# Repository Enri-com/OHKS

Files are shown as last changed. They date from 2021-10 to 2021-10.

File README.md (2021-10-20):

# Open-hardware knob system for acceleration control operations #

## Description

The hardware has been structured on a PCB where are mounted 9 keys and a mechanical encoder.
The keys are used to simulate, at the firmware level, the pressure of one keyboard button or a combination of them. 
Each key is equipped with anti-bounce circuitry and ade-quate ESD protection to prevent a malfunction or breakdown 
of the electronics.
The microcontroller is devoted to managing the USB HID communication. 
To have multiple options in terms of hardware solutions for the microcontroller, the PCB has been realized to be 
compatible with both ARM STM32 microcontroller and Teensy LC module.

## License

Copyright INFN-LNL 2020.
This documentation describes OHKS_WFP hardware and is licensed under the
CERN OHL v. 1.2.
You may redistribute and modify this documentation under the terms of the
CERN OHL v.1.2. (http://ohwr.org/cernohl). This documentation is distributed
WITHOUT ANY EXPRESS OR IMPLIED WARRANTY, INCLUDING OF
MERCHANTABILITY, SATISFACTORY QUALITY AND FITNESS FOR A
PARTICULAR PURPOSE. Please see the CERN OHL v.1.2 for applicable
conditions

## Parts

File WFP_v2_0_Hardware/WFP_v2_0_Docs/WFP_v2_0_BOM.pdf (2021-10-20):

Qty: | Reference(s): | Value: | Part number: | Manufacturer:
2 | C1, C2 | 10pF | 0603 10pF C0G | GENERIC
10 | C3, C4,C5, C6, C7, C9, C10, C11, C12, C13 | 0.1uF | 0603 100nF X7R | GENERIC
1 | C8 | 4.7uF | 0805 4.7uF not polarized multilayer | GENERIC
1 | D1 | BAT54HT1G | BAT54HT1G | ONSEMI
2 | D2, D3 | LED | 0805 Green LED | GENERIC
2 | FB1, FB2 | WURTH_742792608 | 742792608 | WURTH
1 | J1 | Conn_01x05_Male | Connector:Conn_01x05_Male | GENERIC
1 | J2 | Conn_ARM_JTAG_SWD_10 | Connector:Conn_ARM_JTAG_SWD_10 | GENERIC
1 | J3 | USB_B_Micro_WURTH_629105150521 | 629105150521 | WURTH
4 | R1, R2, R3, R7, R23 | 0R0 | 0603 0R0 | GENERIC
15 | R4, R8, R9, R10, R11, R12, R13, R14, R15, R16, R17, R18, R19, R20, R21 | 10K | 0603 10K | GENERIC
2 | R5, R22 | 470R | 0603 470R | GENERIC
1 | R6 | 100K | 0603 100K | GENERIC
2 | SW1, SW2 | B3S-1000 | B3S-1000 | OMRON
9 | SW3, SW4, SW5, SW6, SW7, SW9, SW10, SW11, SW12 | SW_Push | MX1A-11NW | ZF
1 | SW8 | PEC11R-4215F-S24 | PEC11R-4215F-S24 | BOURNS
2 | U1, U5 | IP4220CZ6 | IP4220CZ6 | NEXPERIA
1 | U2 | Teensy-LC | Teensy-LC | PJRC
1 | U3 | STM32F042K6T7 | STM32F042K6T7 | STMICROELECTRONICS
1 | U4 | LM1117-3.3 | LM1117IMP-3.3/NOPB | TI
3 | U6, U7, U8 | SN74HCS125D-Q1 | SN74HCS125-Q | TI
1 | Y1 | NX3225GD-8MHZ-EXS00A-CG04874 | NX3225GD-8MHZ-STD-CRA-3 | NDK

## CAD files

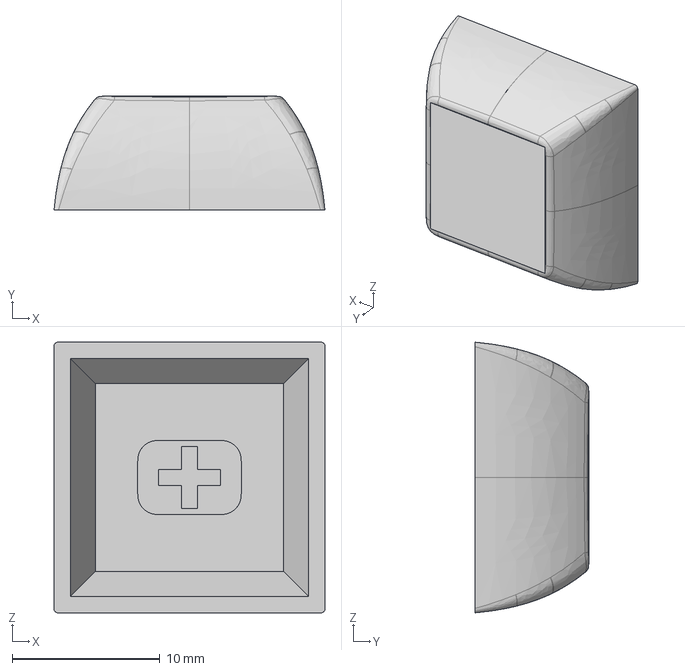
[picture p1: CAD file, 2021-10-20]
WFP_v2_0_3D-Mechanical/Sw_keycap.step
18.3 x 7.70 x 18.3 mm

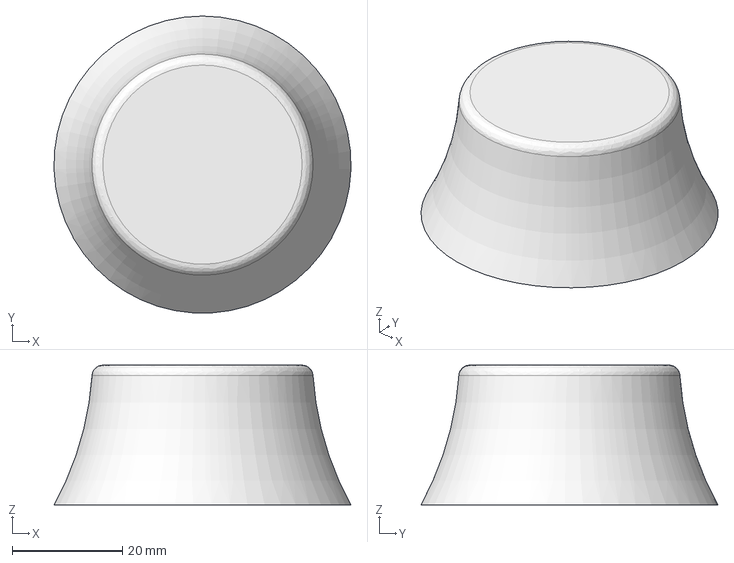
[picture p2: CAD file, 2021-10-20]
WFP_v2_0_3D-Mechanical/Encoder_knob.step
54.0 x 53.9 x 25.4 mm

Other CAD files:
WFP_v2_0_3D-Mechanical/Encoder_knob.stl
WFP_v2_0_3D-Mechanical/Sw_keycap.stl

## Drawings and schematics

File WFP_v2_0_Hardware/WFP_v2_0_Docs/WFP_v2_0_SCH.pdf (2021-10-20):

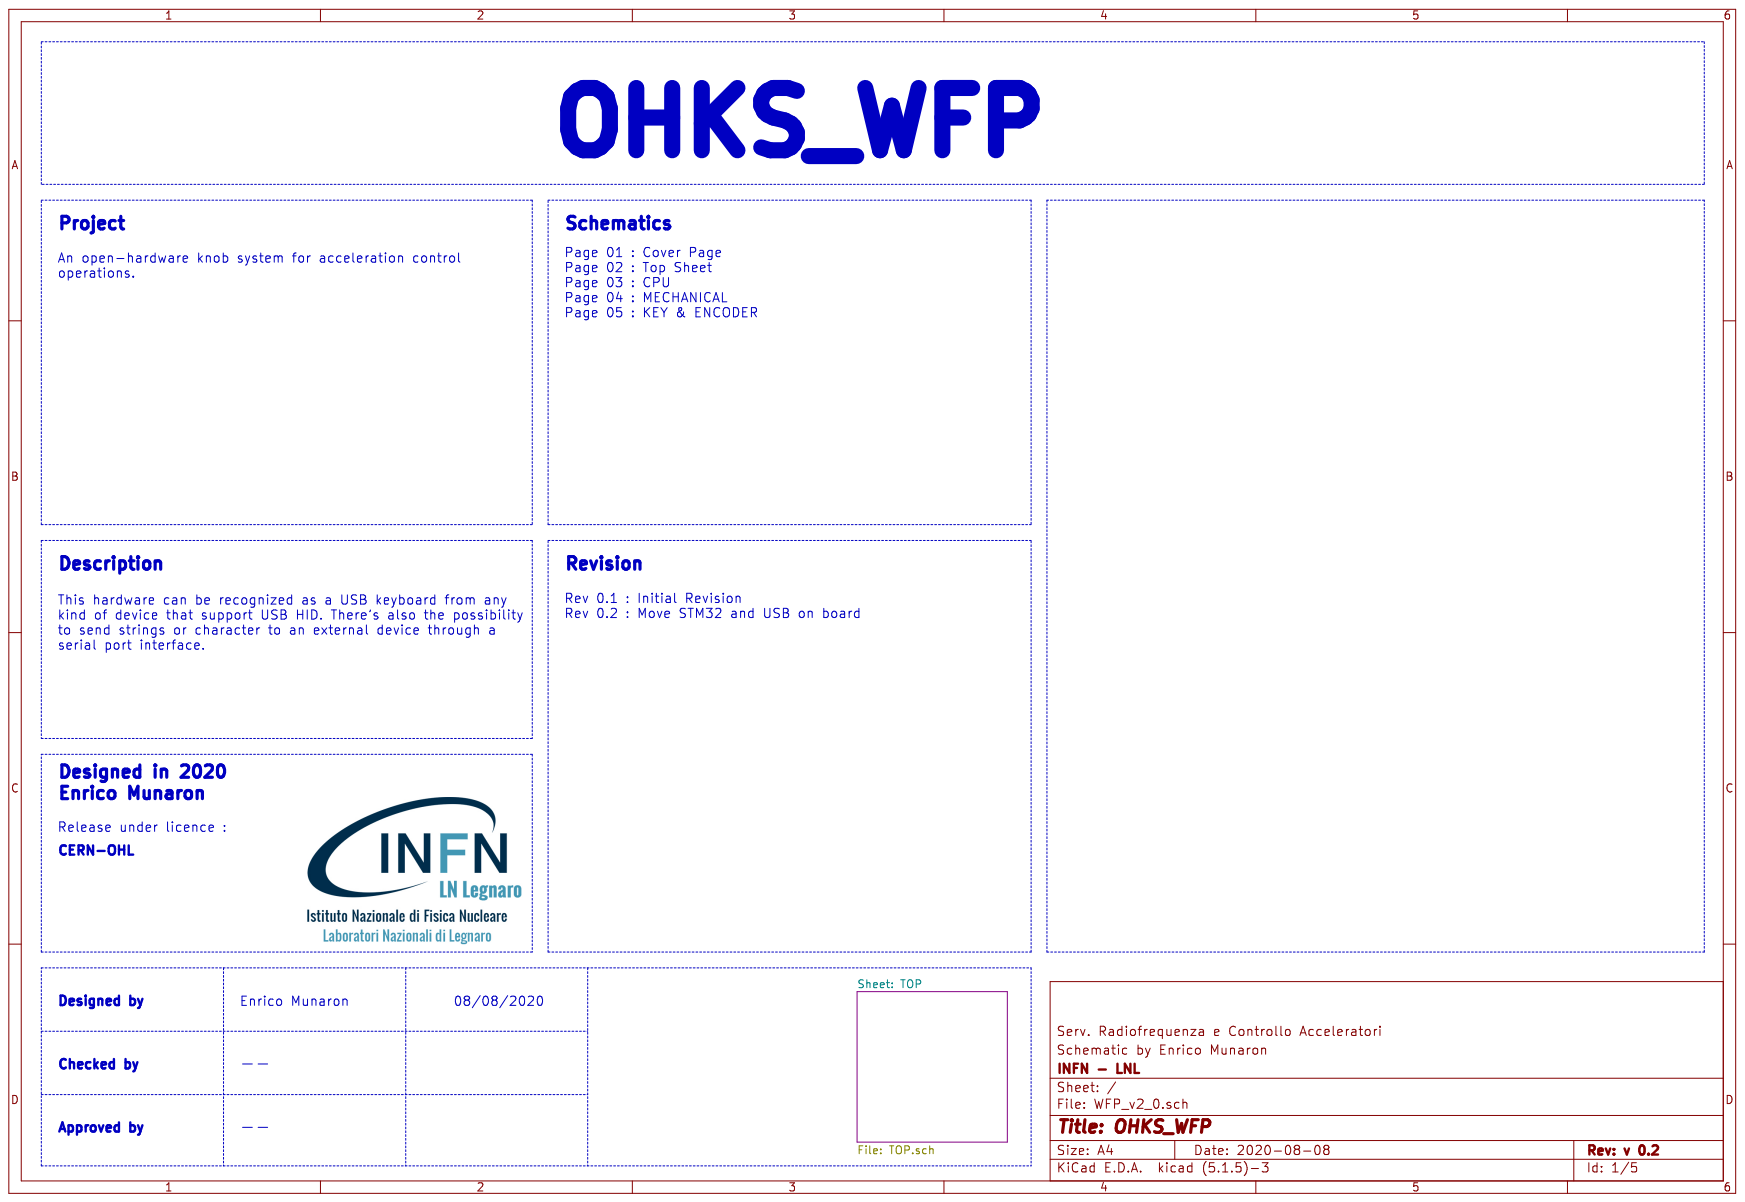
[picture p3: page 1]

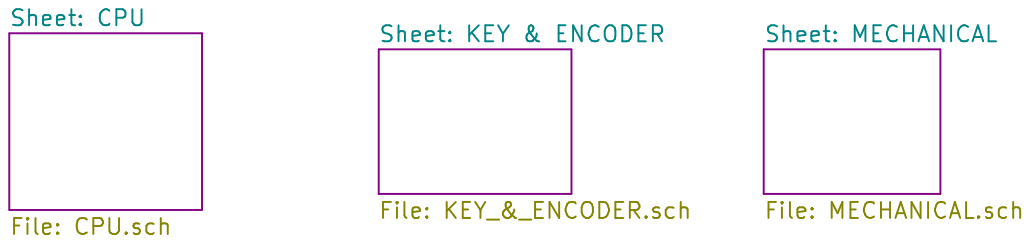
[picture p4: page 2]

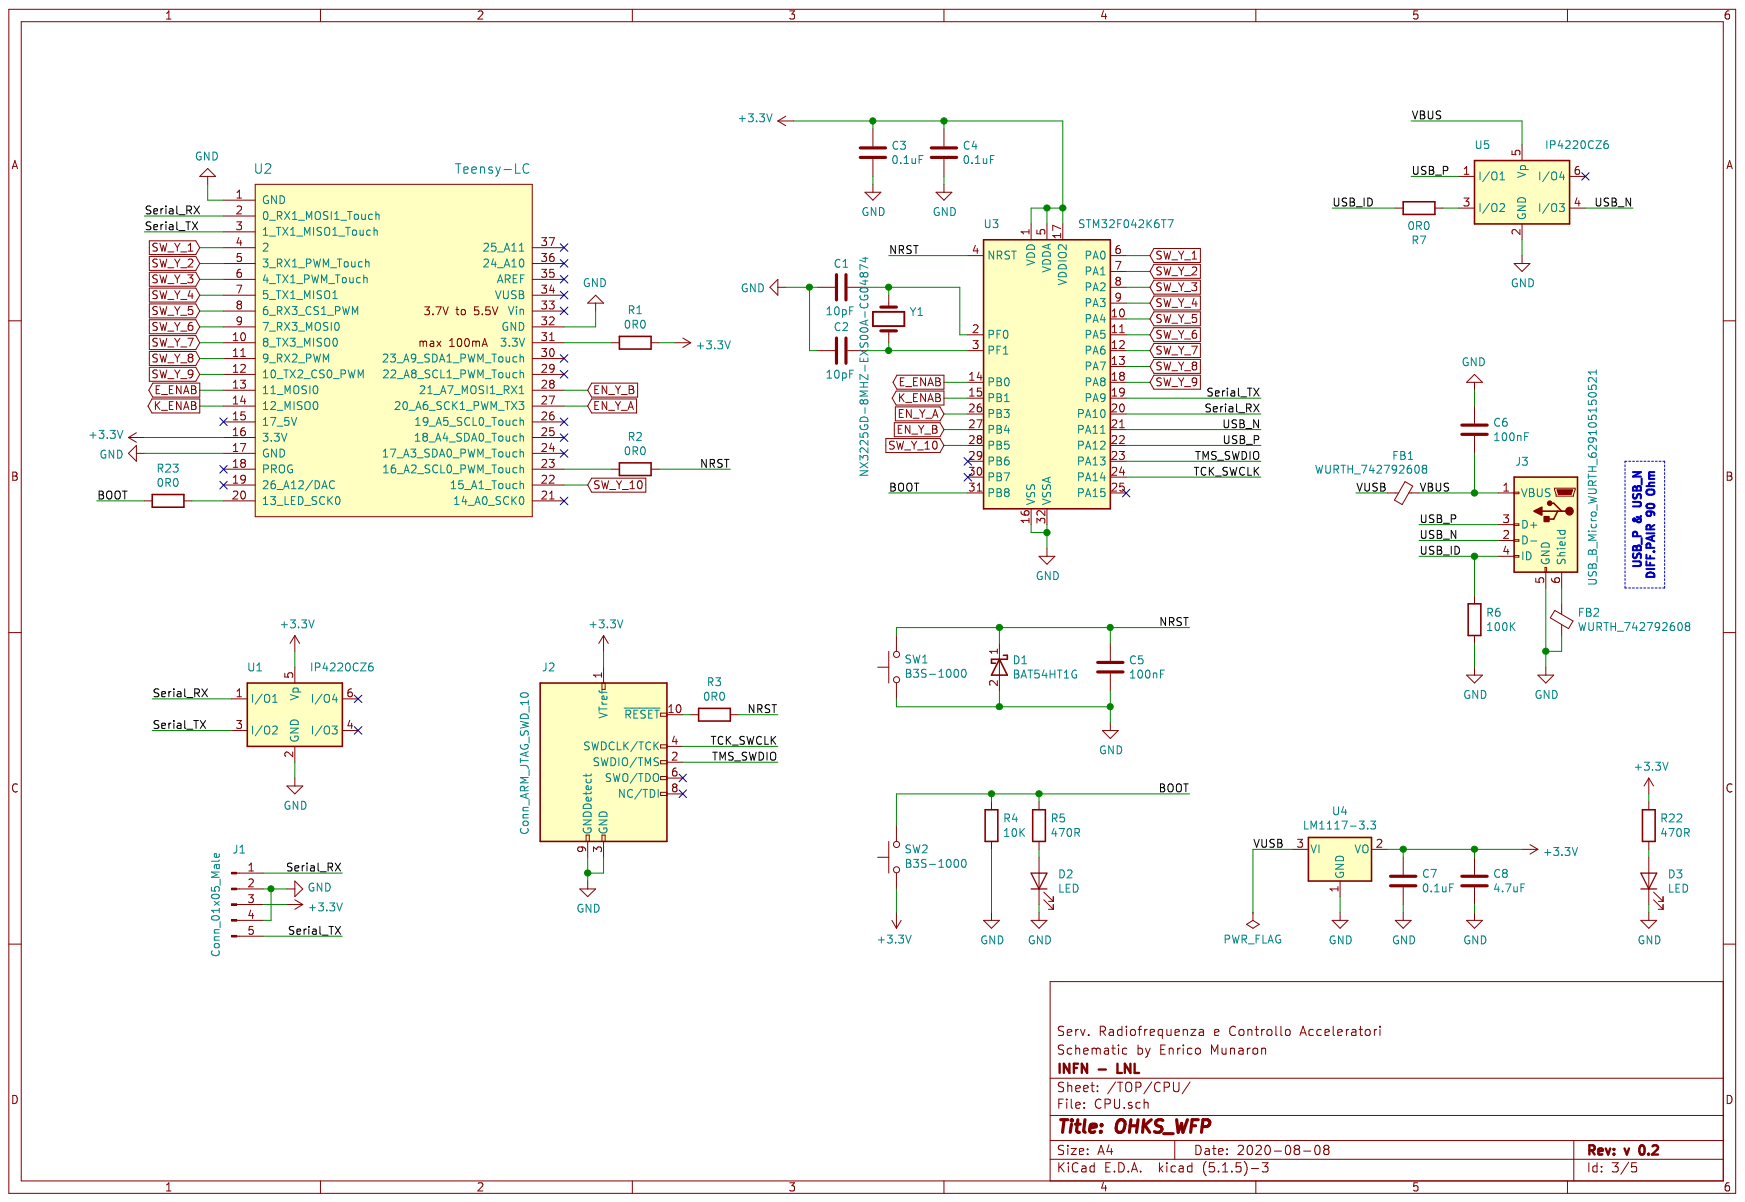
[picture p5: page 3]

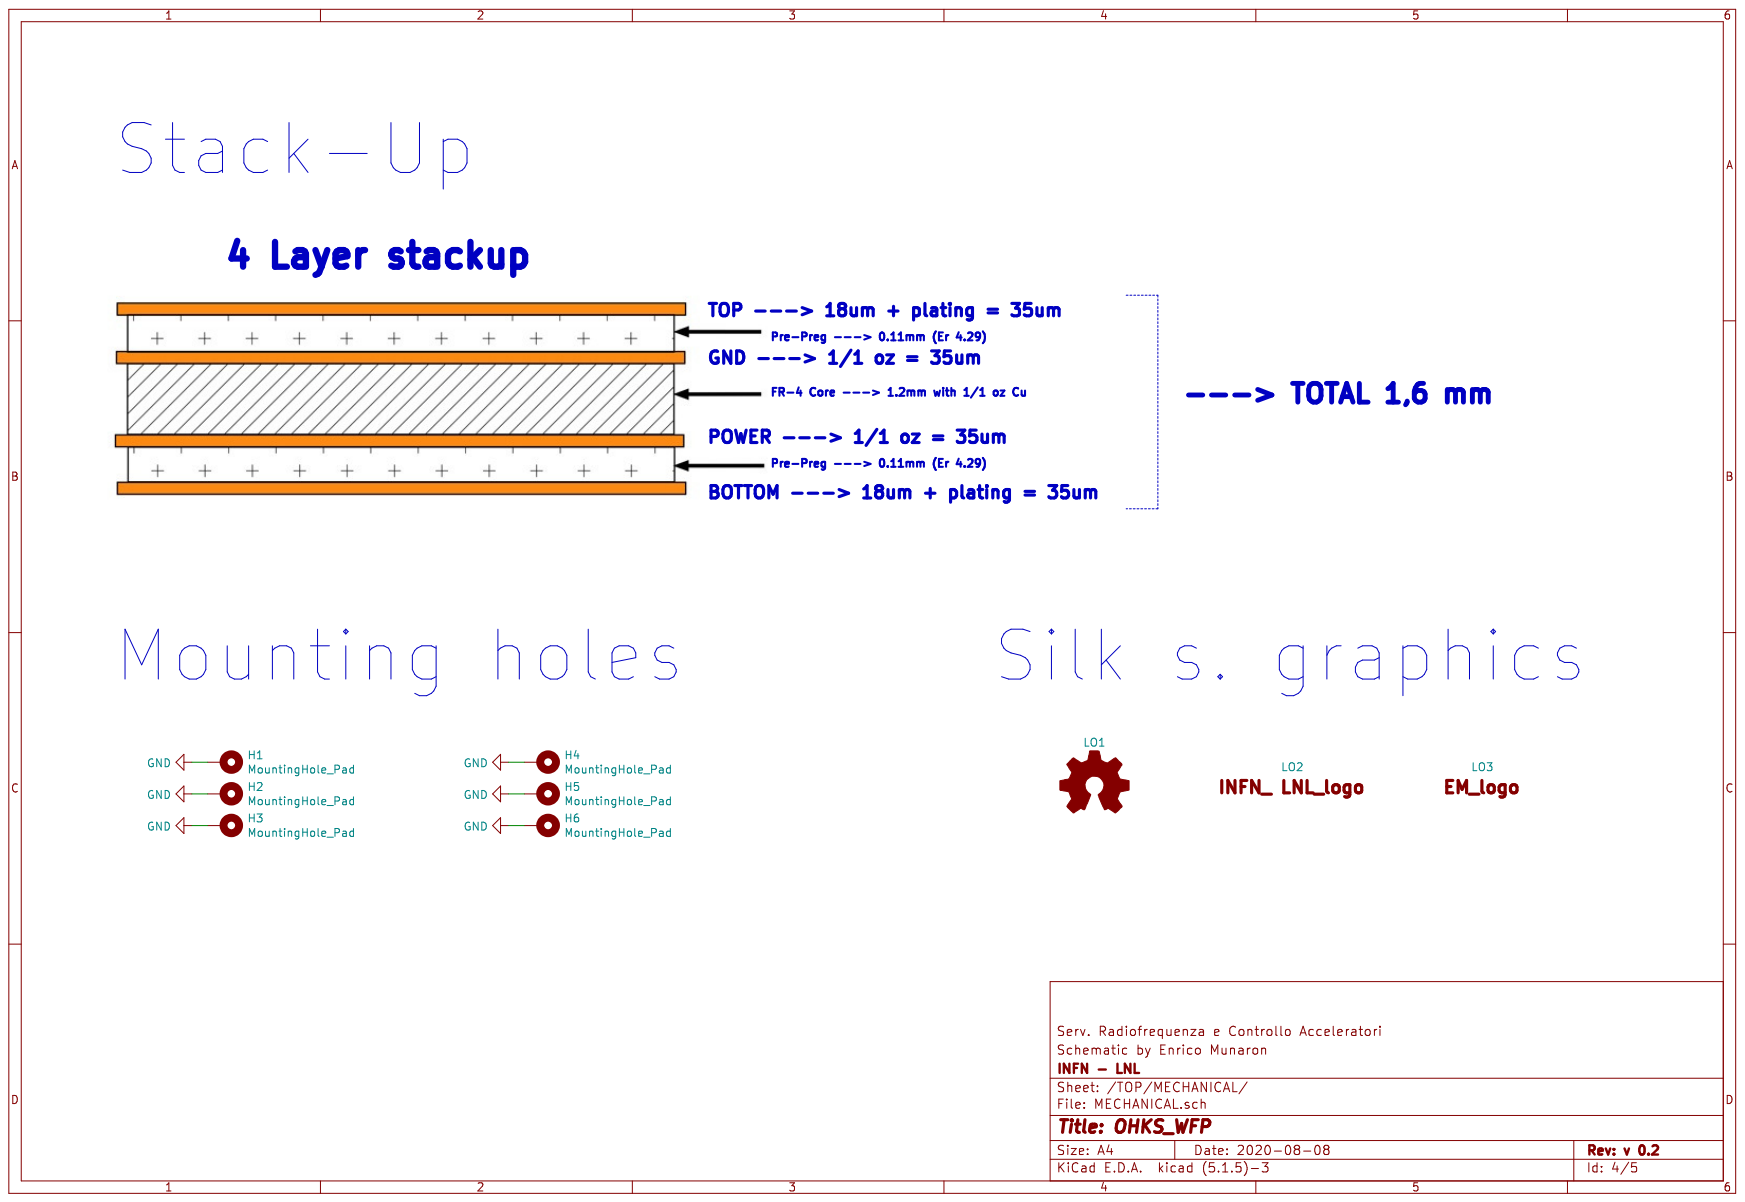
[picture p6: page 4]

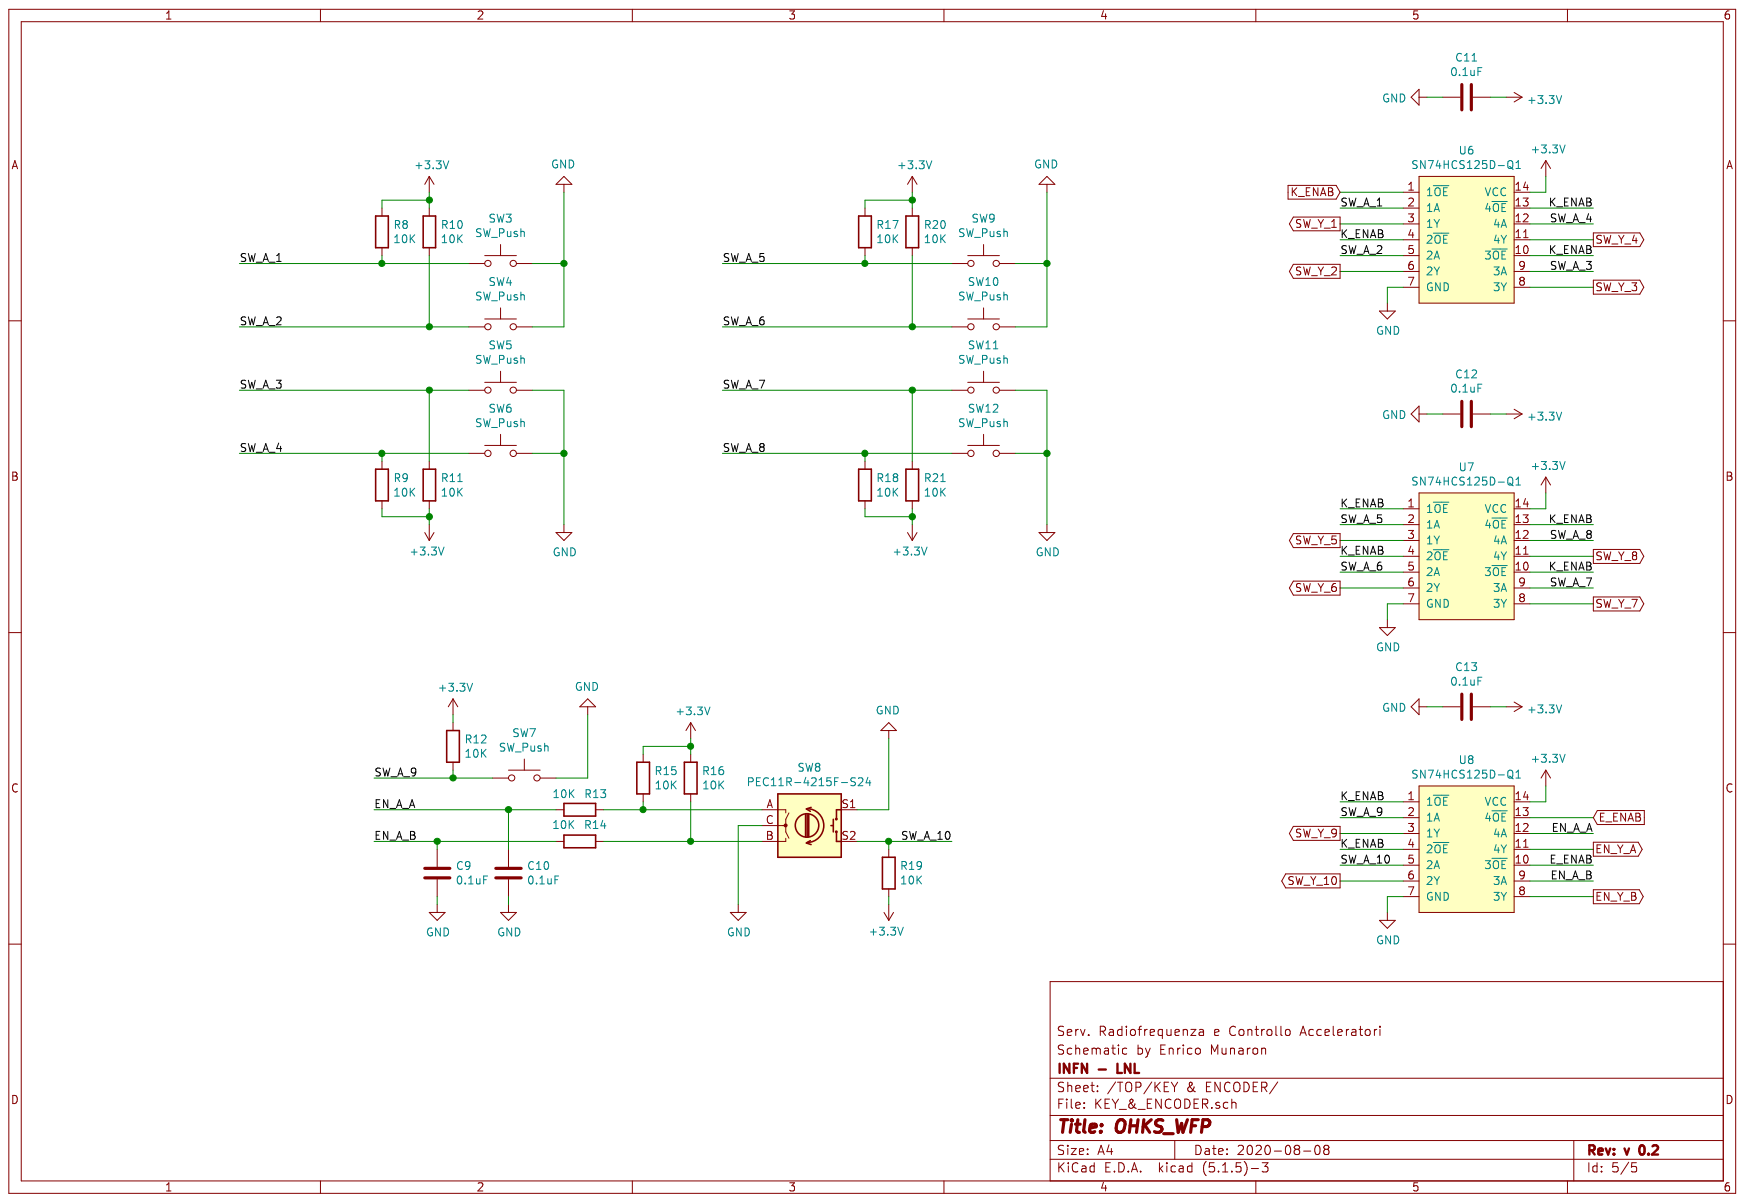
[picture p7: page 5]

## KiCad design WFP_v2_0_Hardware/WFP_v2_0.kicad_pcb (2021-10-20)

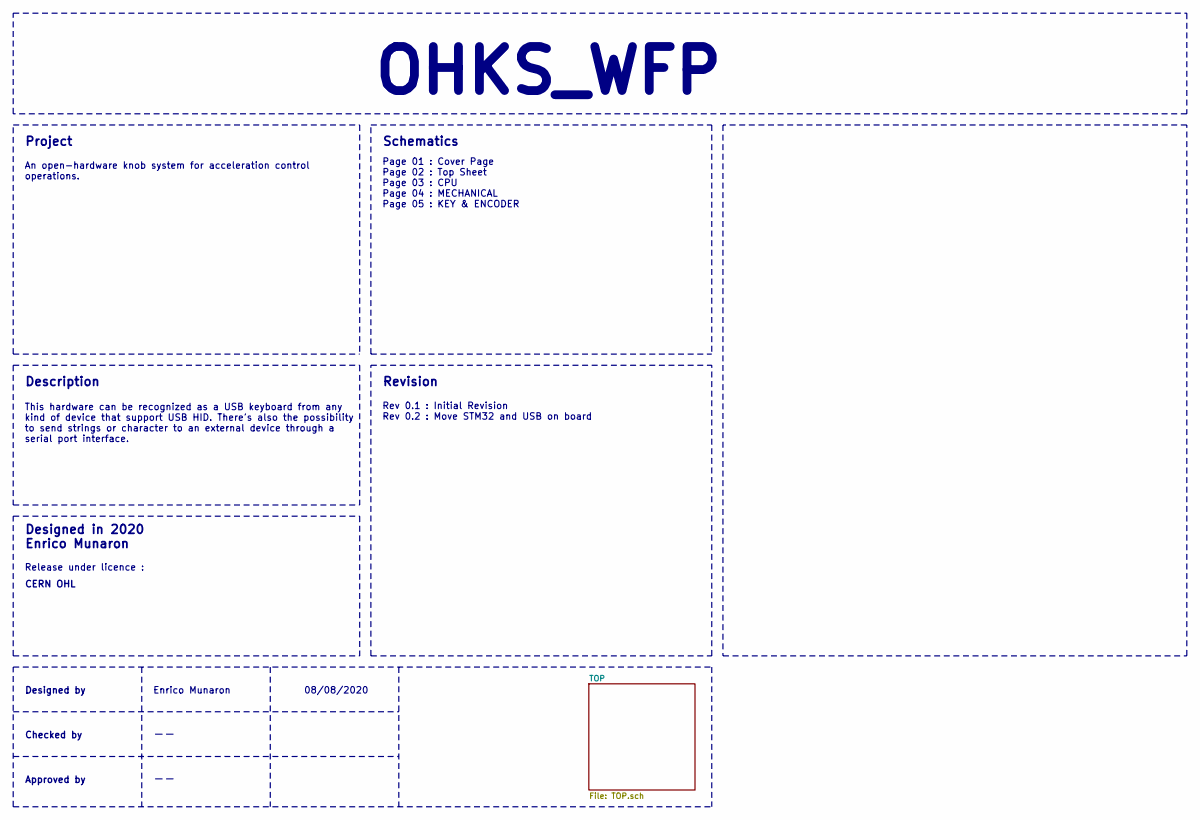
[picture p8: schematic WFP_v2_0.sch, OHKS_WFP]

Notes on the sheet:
OHKS_WFP
Project
Schematics
Description
Designed in 2020 Enrico Munaron
Release under licence :
CERN OHL
This hardware can be recognized as a USB keyboard from any kind of device that support USB HID. There’s also the possibility to send strings or character to an external device through a serial port interface.
An open-hardware knob system for acceleration control operations.
Page 01 : Cover Page Page 02 : Top Sheet Page 03 : CPU Page 04 : MECHANICAL Page 05 : KEY & ENCODER
Revision
Rev 0.1 : Initial Revision Rev 0.2 : Move STM32 and USB on board
Designed by
Checked by
Approved by
Enrico Munaron
08/08/2020

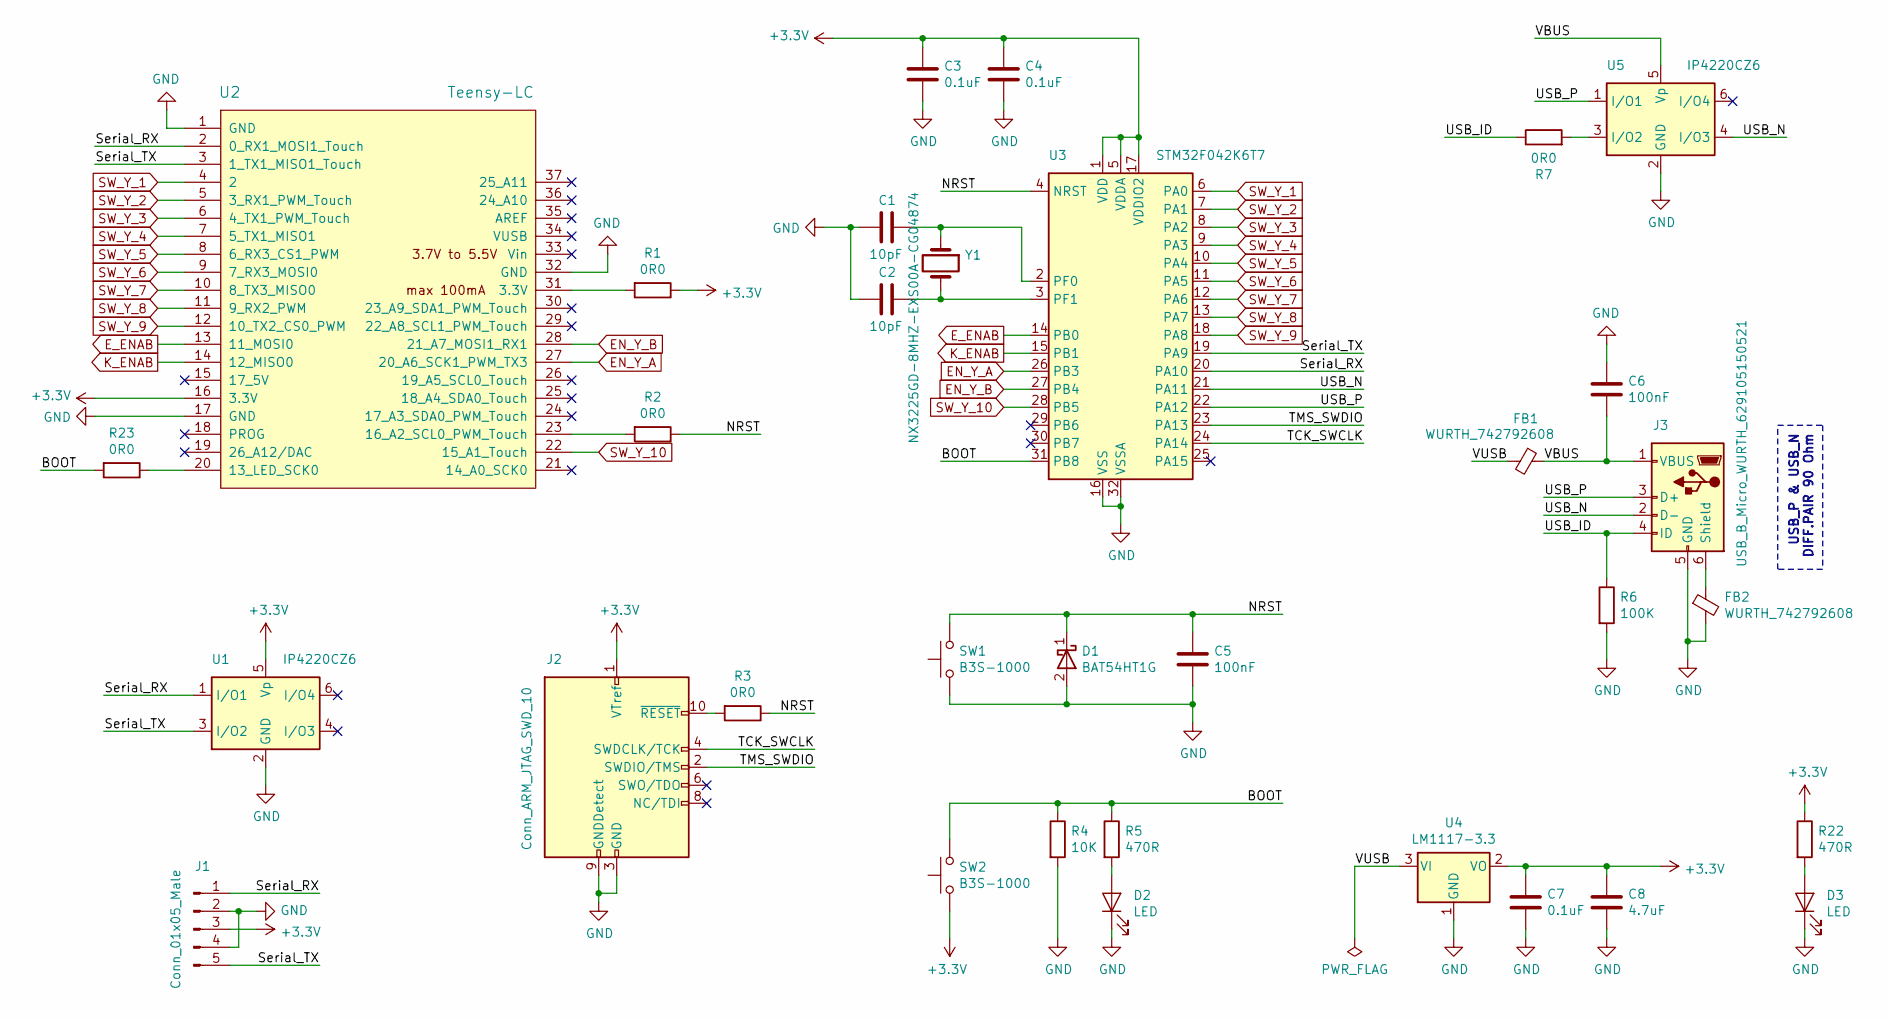
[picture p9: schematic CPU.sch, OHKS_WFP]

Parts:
C1, C2: 10pF; C_0603_1608Metric_Pad1.05x0.95mm_HandSolder
C3, C4, C7: 0.1uF; C_0603_1608Metric_Pad1.05x0.95mm_HandSolder
C5, C6: 100nF; C_0603_1608Metric_Pad1.05x0.95mm_HandSolder
C8: 4.7uF; C_0805_2012Metric_Pad1.15x1.40mm_HandSolder
D1: BAT54HT1G; D_SOD-323_HandSoldering
D2, D3: LED; LED_0805_2012Metric_Pad1.15x1.40mm_HandSolder
FB1, FB2: WURTH_742792608; L_0603_1608Metric_Pad1.05x0.95mm_HandSolder
J1: Conn_01x05_Male; PinHeader_1x05_P2.54mm_Vertical
J2: Conn_ARM_JTAG_SWD_10; PinHeader_2x05_P1.27mm_Vertical_SMD
J3: USB_B_Micro_WURTH_629105150521; USB_Micro-B_Wuerth_629105150521
R1, R2, R3, R7, R23: 0R0; R_0603_1608Metric_Pad1.05x0.95mm_HandSolder
R4: 10K; R_0603_1608Metric_Pad1.05x0.95mm_HandSolder
R5, R22: 470R; R_0603_1608Metric_Pad1.05x0.95mm_HandSolder
R6: 100K; R_0603_1608Metric_Pad1.05x0.95mm_HandSolder
SW1, SW2: B3S-1000; Omron_B3S-1000
U1, U5: IP4220CZ6; SOT-457
U2: Teensy-LC; Teensy_LC
U3: STM32F042K6T7; LQFP-32_7x7mm_P0.8mm
U4: LM1117-3.3; SOT-223-3_TabPin2
Y1: NX3225GD-8MHZ-EXS00A-CG04874; Crystal_SMD_3225-2Pin_3.2x2.5mm

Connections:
+3V3: C3.1, C4.1, C7.1, C8.1, J1.3, J2.1 (VTref), R1.1, R22.1, SW2.1, U1.5 (Vp), U2.16 (3.3V), U3.1 (VDD), U3.5 (VDDA), U3.17 (VDDIO2), U4.2 (VO); also elsewhere on the board
/TOP/CPU/BOOT: R4.1, R5.1, R23.2, SW2.2, U3.31 (PB8)
/TOP/CPU/NRST: C5.1, D1.1 (K), R2.1, R3.1, SW1.2, U3.4 (NRST)
/TOP/CPU/Serial_RX: J1.1, U1.1 (I/O1), U2.2 (0_RX1_MOSI1_Touch), U3.20 (PA10)
/TOP/CPU/Serial_TX: J1.5, U1.3 (I/O2), U2.3 (1_TX1_MISO1_Touch), U3.19 (PA9)
/TOP/CPU/TCK_SWCLK: J2.4 (SWDCLK/TCK), U3.24 (PA14)
/TOP/CPU/TMS_SWDIO: J2.2 (SWDIO/TMS), U3.23 (PA13)
/TOP/CPU/USB_ID: J3.4 (ID), R6.1, R7.1
/TOP/CPU/USB_N: J3.2 (D-), U3.21 (PA11), U5.4 (I/O3)
/TOP/CPU/USB_P: J3.3 (D+), U3.22 (PA12), U5.1 (I/O1)
/TOP/CPU/VBUS: C6.2, FB1.1, J3.1 (VBUS), U5.5 (Vp)
/TOP/CPU/VUSB: FB1.2, U4.3 (VI)
EN_Y_A: U2.27 (20_A6_SCK1_PWM_TX3), U3.26 (PB3); also elsewhere on the board
EN_Y_B: U2.28 (21_A7_MOSI1_RX1), U3.27 (PB4); also elsewhere on the board
E_ENAB: U2.13 (11_MOSI0), U3.14 (PB0); also elsewhere on the board
GND: C1.2, C2.2, C3.2, C4.2, C5.2, C6.1, C7.2, C8.2, D1.2 (A), D2.1 (K), D3.1 (K), FB2.2, J1.2, J1.4, J2.3 (GND), J2.5 (GND), J2.9 (GNDDetect), J3.5 (GND), R4.2, R6.2, SW1.1, U1.2 (GND), U2.1 (GND), U2.17 (GND), U2.32 (GND), U3.16 (VSS), U3.32 (VSSA), U4.1 (GND), U5.2 (GND); also elsewhere on the board
K_ENAB: U2.14 (12_MISO0), U3.15 (PB1); also elsewhere on the board
unnamed: C1.1, U3.2 (PF0), Y1.1
unnamed: C2.1, U3.3 (PF1), Y1.2
unnamed: D2.2 (A), R5.2
unnamed: D3.2 (A), R22.2
unnamed: FB2.1, J3.6 (Shield)
unnamed: J2.10 (~RESET~), R3.2
unnamed: R1.2, U2.31 (3.3V)
unnamed: R2.2, U2.23 (16_A2_SCL0_PWM_Touch)
unnamed: R7.2, U5.3 (I/O2)
unnamed: R23.1, U2.20 (13_LED_SCK0)
SW_Y_1: U2.4 (2), U3.6 (PA0); also elsewhere on the board
SW_Y_2: U2.5 (3_RX1_PWM_Touch), U3.7 (PA1); also elsewhere on the board
SW_Y_3: U2.6 (4_TX1_PWM_Touch), U3.8 (PA2); also elsewhere on the board
SW_Y_4: U2.7 (5_TX1_MISO1), U3.9 (PA3); also elsewhere on the board
SW_Y_5: U2.8 (6_RX3_CS1_PWM), U3.10 (PA4); also elsewhere on the board
SW_Y_6: U2.9 (7_RX3_MOSI0), U3.11 (PA5); also elsewhere on the board
SW_Y_7: U2.10 (8_TX3_MISO0), U3.12 (PA6); also elsewhere on the board
SW_Y_8: U2.11 (9_RX2_PWM), U3.13 (PA7); also elsewhere on the board
SW_Y_9: U2.12 (10_TX2_CS0_PWM), U3.18 (PA8); also elsewhere on the board
SW_Y_10: U2.22 (15_A1_Touch), U3.28 (PB5); also elsewhere on the board

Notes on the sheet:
USB_P & USB_N DIFF.PAIR 90 Ohm

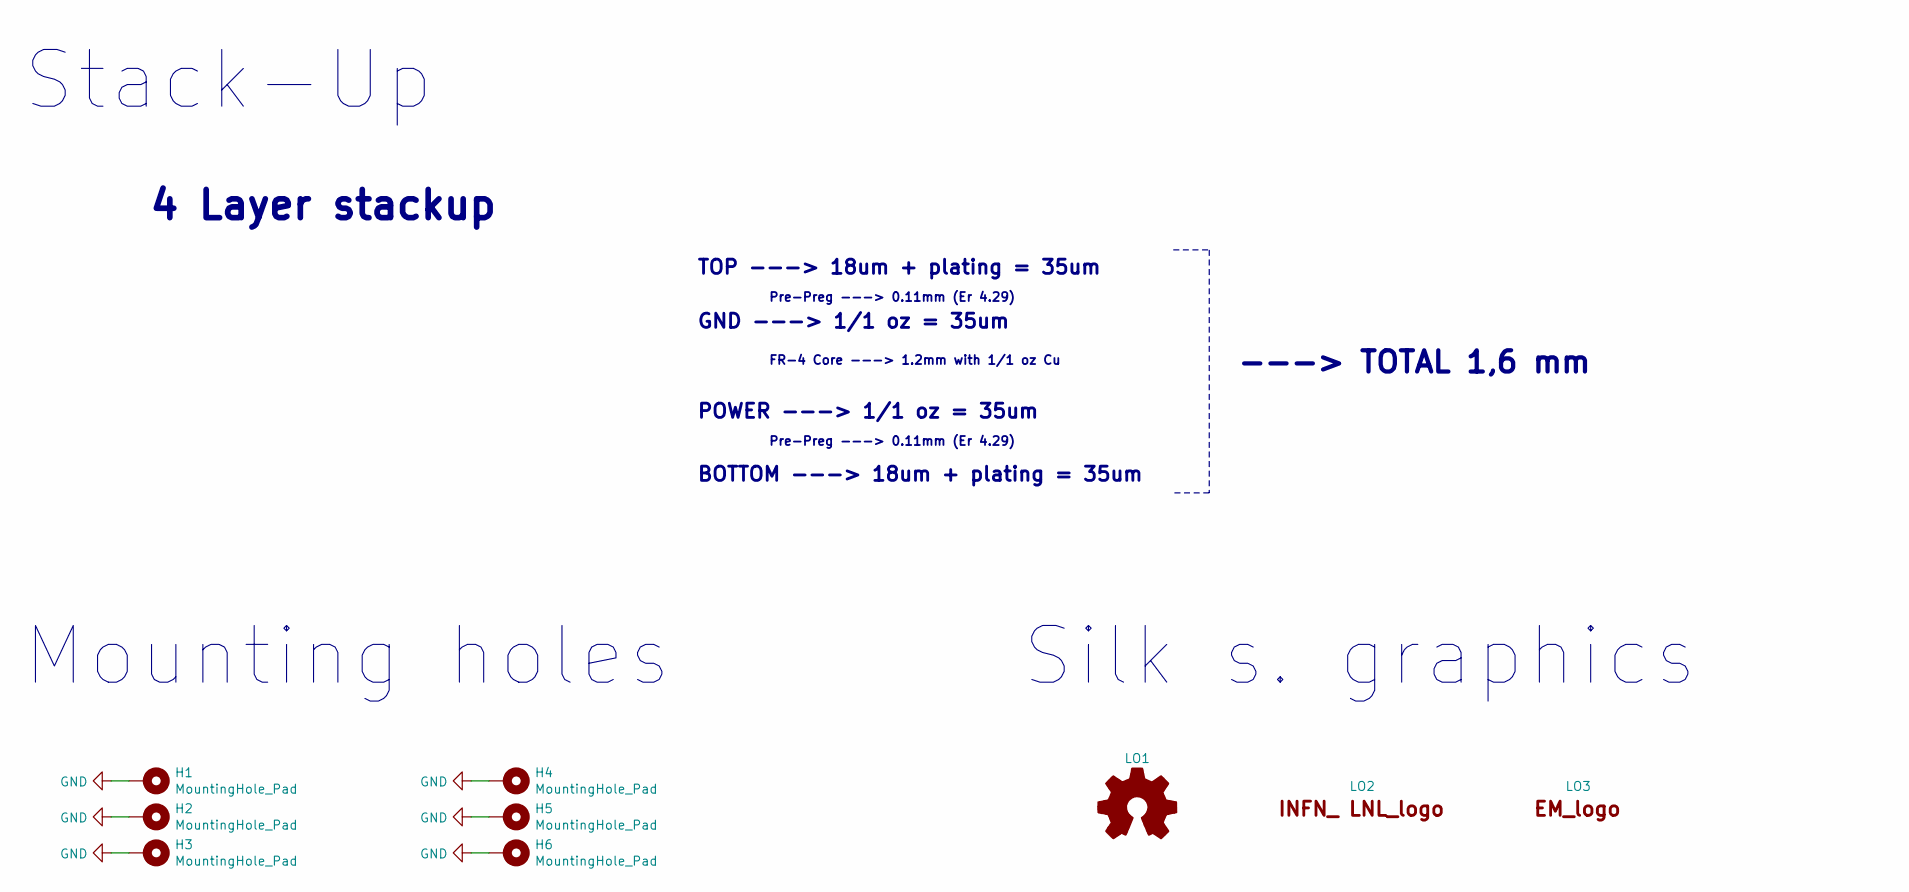
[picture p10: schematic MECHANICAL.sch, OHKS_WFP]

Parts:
H1, H2, H3, H4, H5, H6: MountingHole_Pad; MountingHole_3.2mm_M3_Pad_Via
LO1: Logo_Open_Hardware_Small; OSHW-Logo_5.7x6mm_SilkScreen
LO2: Logo_INFN_LNL; INFN_LNL_Logo
LO3: Logo_EM; EM_Logo_13x9

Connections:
GND: H1.1, H2.1, H3.1, H4.1, H5.1, H6.1; also elsewhere on the board

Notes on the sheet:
Pre-Preg ---> 0.11mm (Er 4.29)
TOP ---> 18um + plating = 35um
GND ---> 1/1 oz = 35um
POWER ---> 1/1 oz = 35um
BOTTOM ---> 18um + plating = 35um
FR-4 Core ---> 1.2mm with 1/1 oz Cu
4 Layer stackup
Stack-Up
Mounting holes
Silk s. graphics
---> TOTAL 1,6 mm

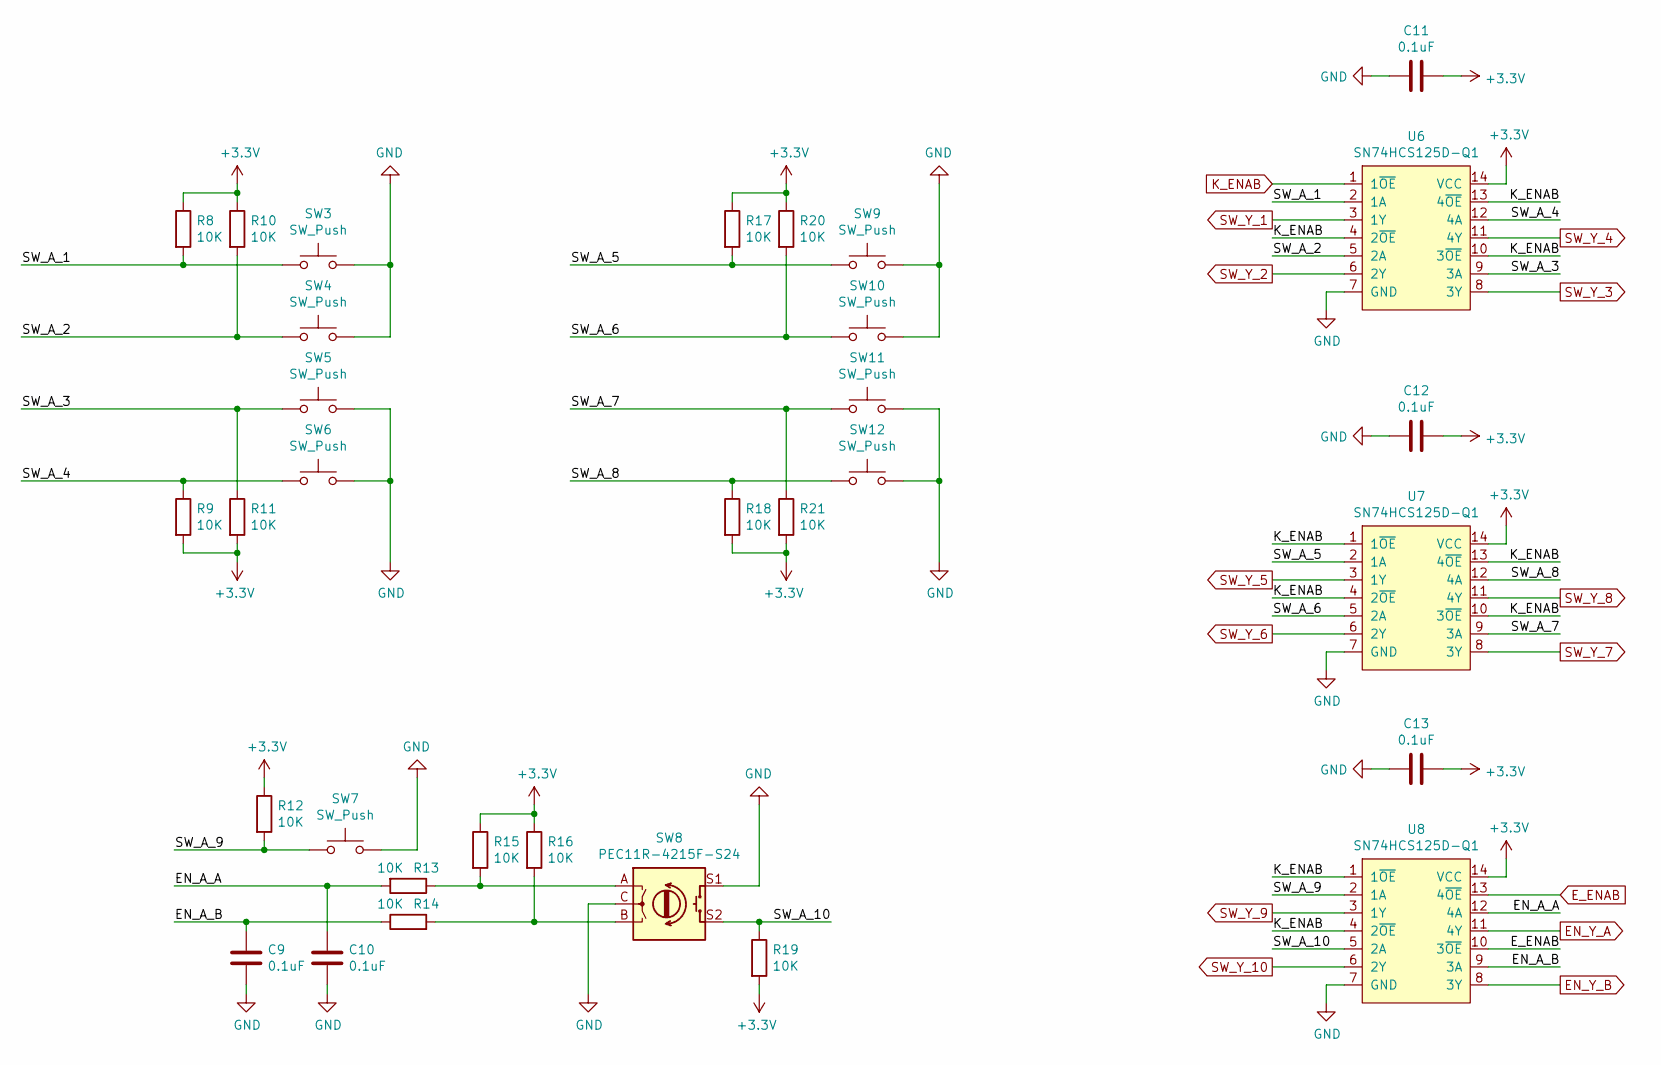
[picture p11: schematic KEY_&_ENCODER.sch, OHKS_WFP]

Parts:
C9, C10, C11, C12, C13: 0.1uF; C_0603_1608Metric_Pad1.05x0.95mm_HandSolder
R8, R9, R10, R11, R12, R13, R14, R15, R16, R17, R18, R19, R20, R21: 10K; R_0603_1608Metric_Pad1.05x0.95mm_HandSolder
SW3, SW4, SW5, SW6, SW7, SW9, SW10, SW11, SW12: SW_Push; SW_Cherry_MX_1.00u_PCB
SW8: PEC11R-4215F-S24; PEC11R
U6, U7, U8: SN74HCS125D-Q1; SOIC-14_3.9x8.7mm_P1.27mm

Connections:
+3V3: C11.1, C12.1, C13.1, R8.1, R9.2, R10.1, R11.2, R12.1, R15.1, R16.1, R17.1, R18.2, R19.2, R20.1, R21.2, U6.14 (VCC), U7.14 (VCC), U8.14 (VCC); also elsewhere on the board
/TOP/KEY & ENCODER/EN_A_A: C10.1, R13.2, U8.12 (4A)
/TOP/KEY & ENCODER/EN_A_B: C9.1, R14.1, U8.9 (3A)
/TOP/KEY & ENCODER/SW_A_1: R8.2, SW3.1, U6.2 (1A)
/TOP/KEY & ENCODER/SW_A_2: R10.2, SW4.1, U6.5 (2A)
/TOP/KEY & ENCODER/SW_A_3: R11.1, SW5.1, U6.9 (3A)
/TOP/KEY & ENCODER/SW_A_4: R9.1, SW6.1, U6.12 (4A)
/TOP/KEY & ENCODER/SW_A_5: R17.2, SW9.1, U7.2 (1A)
/TOP/KEY & ENCODER/SW_A_6: R20.2, SW10.1, U7.5 (2A)
/TOP/KEY & ENCODER/SW_A_7: R21.1, SW11.1, U7.9 (3A)
/TOP/KEY & ENCODER/SW_A_8: R18.1, SW12.1, U7.12 (4A)
/TOP/KEY & ENCODER/SW_A_9: R12.2, SW7.1, U8.2 (1A)
/TOP/KEY & ENCODER/SW_A_10: R19.1, SW8.S2, U8.5 (2A)
EN_Y_A: U8.11 (4Y); also elsewhere on the board
EN_Y_B: U8.8 (3Y); also elsewhere on the board
E_ENAB: U8.10 (3~OE), U8.13 (4~OE); also elsewhere on the board
GND: C9.2, C10.2, C11.2, C12.2, C13.2, SW3.2, SW4.2, SW5.2, SW6.2, SW7.2, SW8.C, SW8.S1, SW9.2, SW10.2, SW11.2, SW12.2, U6.7 (GND), U7.7 (GND), U8.7 (GND); also elsewhere on the board
K_ENAB: U6.1 (1~OE), U6.4 (2~OE), U6.10 (3~OE), U6.13 (4~OE), U7.1 (1~OE), U7.4 (2~OE), U7.10 (3~OE), U7.13 (4~OE), U8.1 (1~OE), U8.4 (2~OE); also elsewhere on the board
unnamed: R13.1, R15.2, SW8.A
unnamed: R14.2, R16.2, SW8.B
SW_Y_1: U6.3 (1Y); also elsewhere on the board
SW_Y_2: U6.6 (2Y); also elsewhere on the board
SW_Y_3: U6.8 (3Y); also elsewhere on the board
SW_Y_4: U6.11 (4Y); also elsewhere on the board
SW_Y_5: U7.3 (1Y); also elsewhere on the board
SW_Y_6: U7.6 (2Y); also elsewhere on the board
SW_Y_7: U7.8 (3Y); also elsewhere on the board
SW_Y_8: U7.11 (4Y); also elsewhere on the board
SW_Y_9: U8.3 (1Y); also elsewhere on the board
SW_Y_10: U8.6 (2Y); also elsewhere on the board

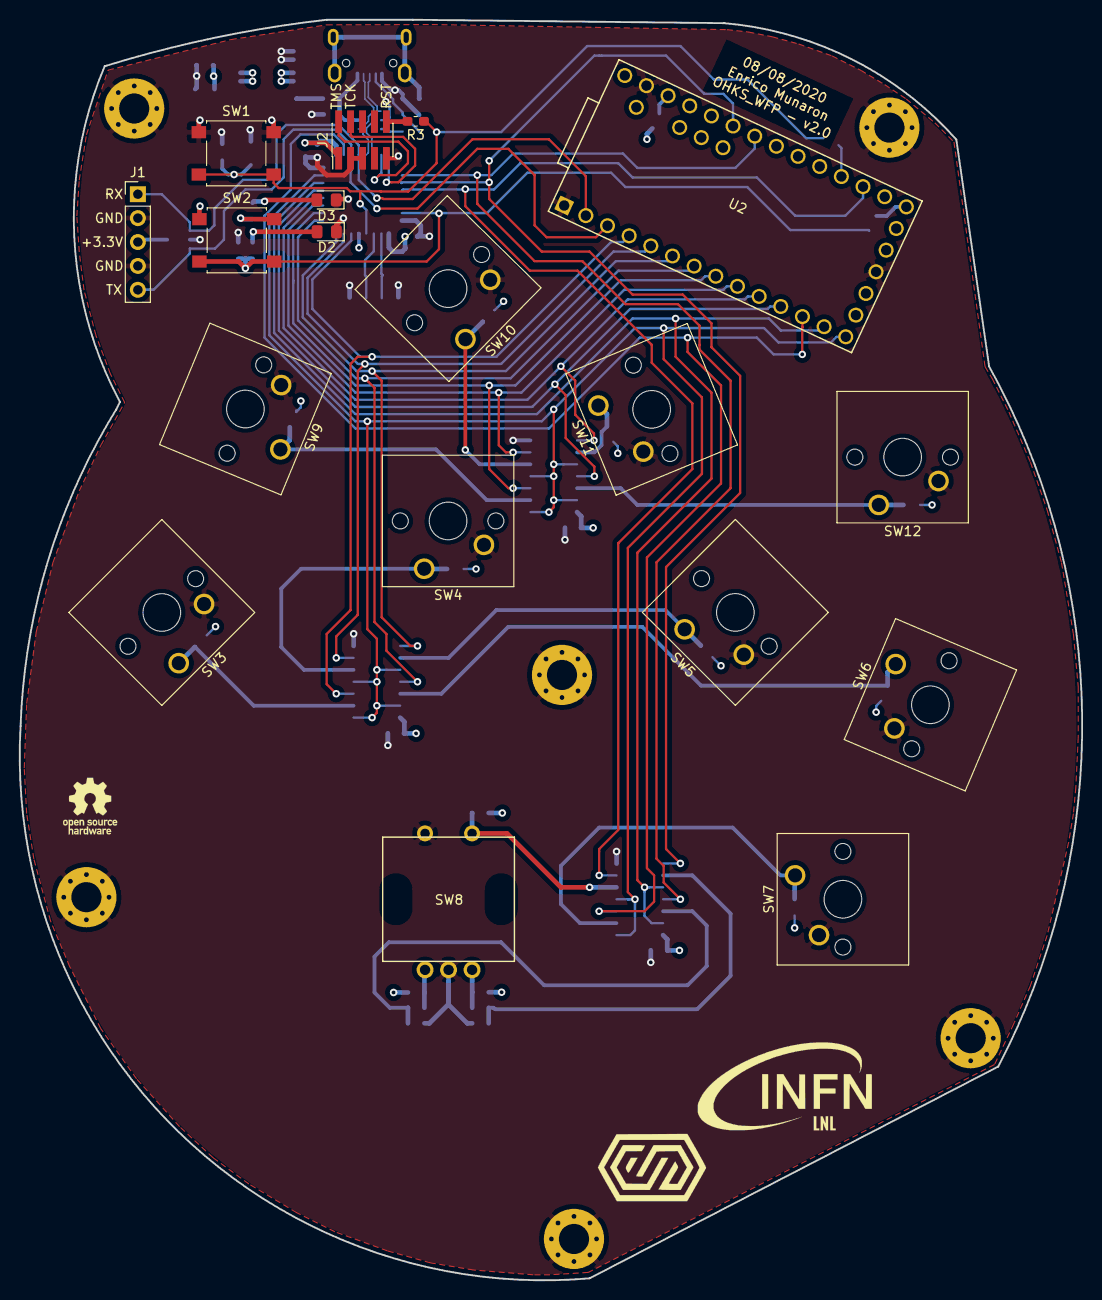
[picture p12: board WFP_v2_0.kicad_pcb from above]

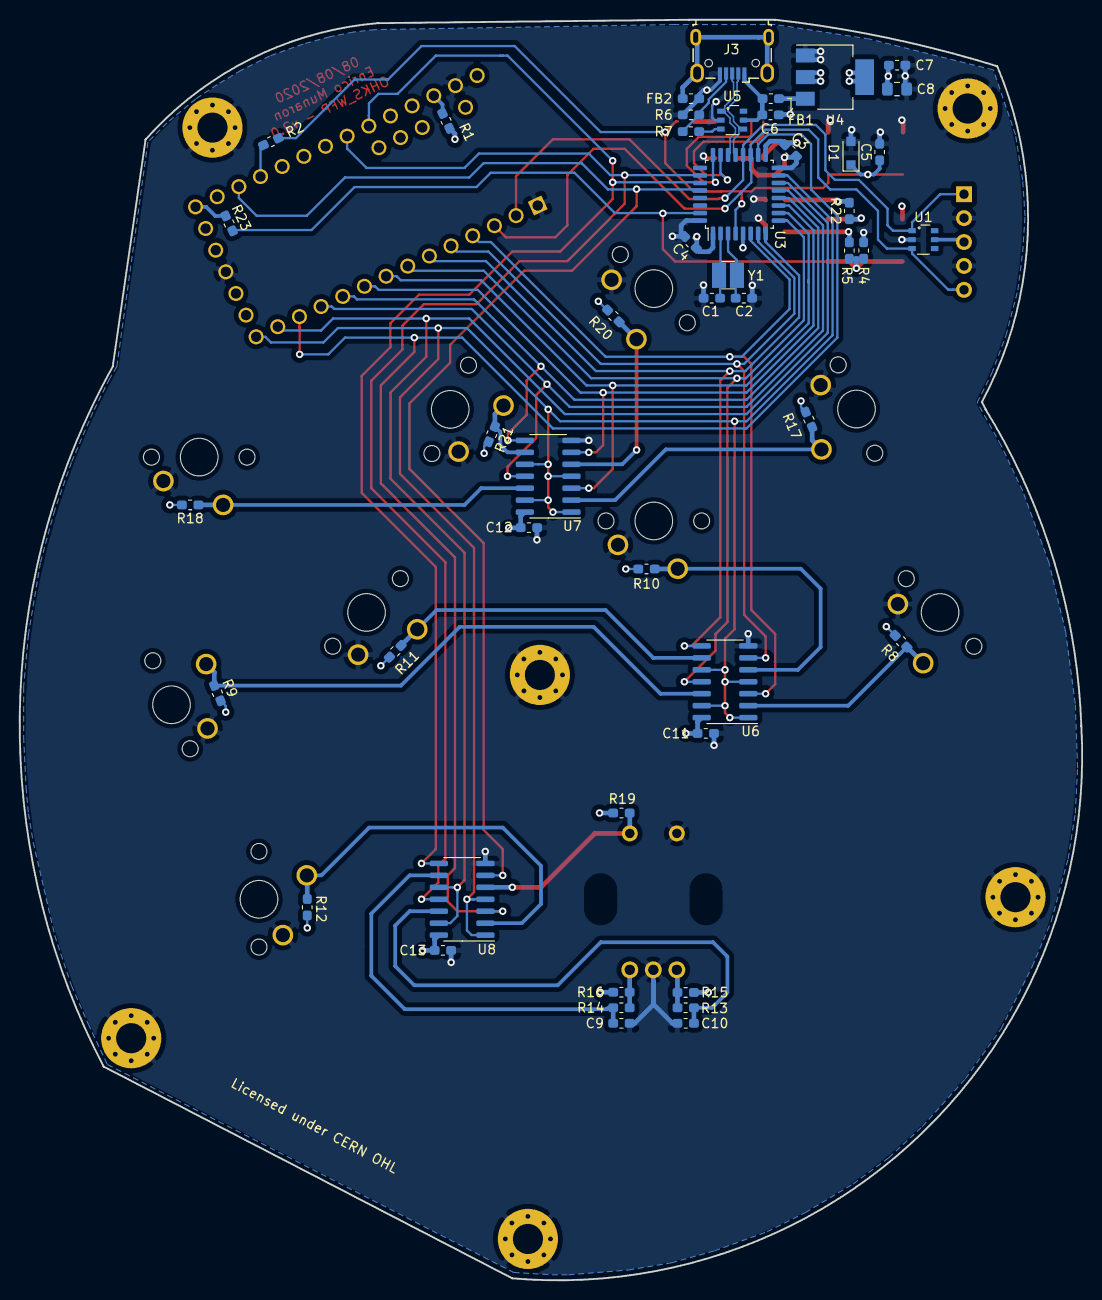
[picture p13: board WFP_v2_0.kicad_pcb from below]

Board: 4 copper layers, 112.9 x 134.0 mm, 74 parts (47 on the bottom side), 51 nets.

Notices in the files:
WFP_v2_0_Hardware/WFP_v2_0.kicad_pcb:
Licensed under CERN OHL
